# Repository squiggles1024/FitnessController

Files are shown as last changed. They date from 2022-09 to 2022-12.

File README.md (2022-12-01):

# FitnessController

This is an implementation of a BLE Gamepad. The purpose was to design a game pad that could be used while running on a treadmill. It would interface with a heartrate monitor strapped to someone's chest and it would pause your game and stop if your heart rate dropped below certain threshold. The microcontroller board is an B-L475E-IOT01A STM32 Discovery board. The firmware is a bare metal implementation of the "HID Over GATT" profile, which, at a minimum, requires a HID Service, Battery Service, and Device info service.
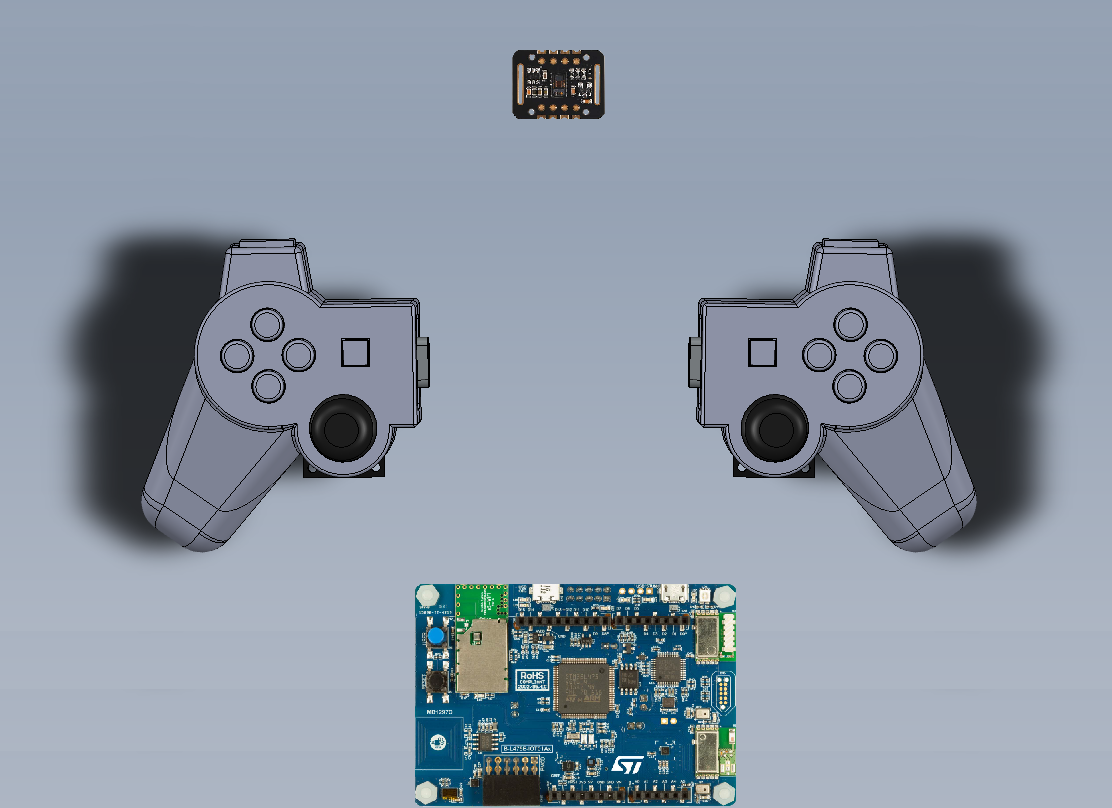
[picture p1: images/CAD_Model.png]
CAD Model Full

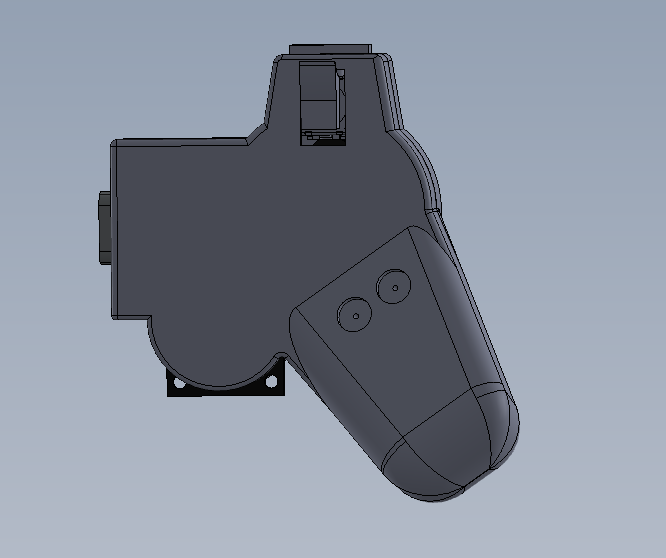
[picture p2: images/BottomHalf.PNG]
CAD Model Bottom


The mechanical design is my own, but it is clearly based on Sony's dual shock controller. I took a pair of calipers and took various measurements to imitate the design. Essentially I set out to cross the dualshock controller with a Wii Nunchuck by splitting a dual shock controller in two halves and putting a D-Sub connector on the sides. The joystick is an off-the-shelf joystick module which I cut the corners off of to make it fit in the housing. The triggers are also joystick modules, but turned upside down and mechanically secured such that it can only move along a single axis. This is a "PCBless" design, all the leads on the components are tied directly to the connector, and wires are spliced together so they can share power/ground signals.
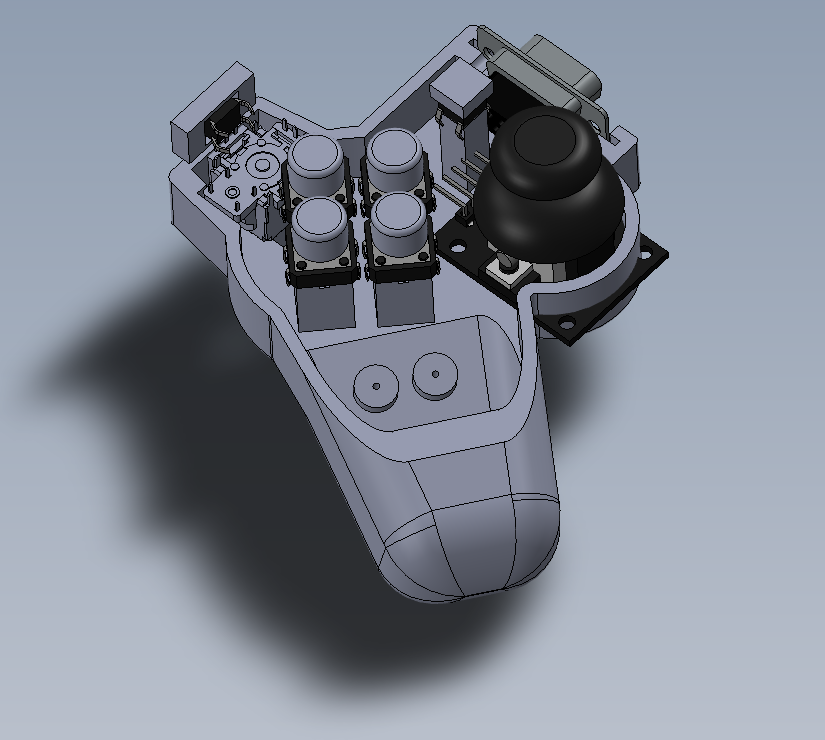
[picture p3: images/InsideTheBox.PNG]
CAD Model Inside


Known Issues: The heart rate monitor is currently NYI as I attempt to debug a hardfault that occurs during initialization of the I2C bus. Currently it only works with Linux based devices, (Windows not yet tested), and does not work with iOS. The controller does not show up to pair with iOS devices when it advertises itself. Likely it does not meet Apple's security requirements, but I haven't found any iOS BLE HID developement guidelines from Apple so I don't know for certain. All I've found is: "BLE HID data is consumed at the OS Kernel level of iOS" which only explains why it won't show up using the LightBlue BLE scanner app.

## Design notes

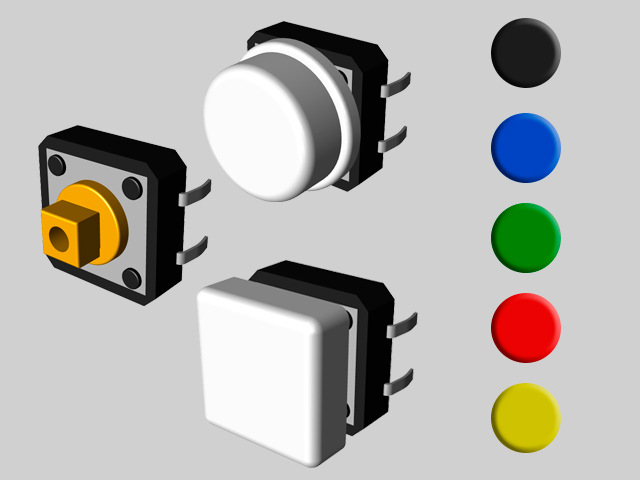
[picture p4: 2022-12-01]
CAD Models/12mm-button-without-cap-with-round-square-cap-1.snapshot.3/img.jpg

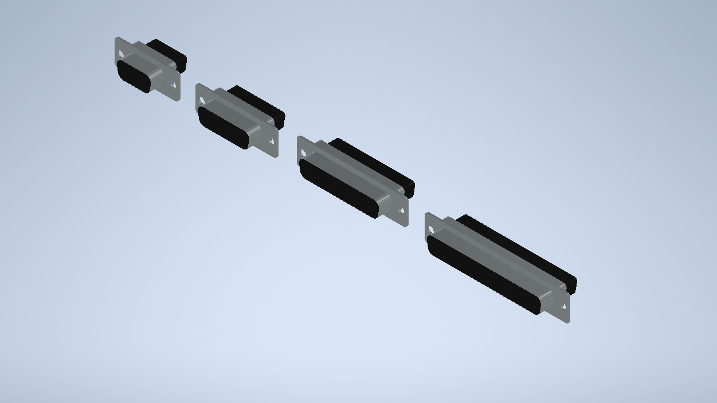
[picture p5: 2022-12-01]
CAD Models/d-sub-connector-femaile-1.snapshot.1/femaile/db.PNG

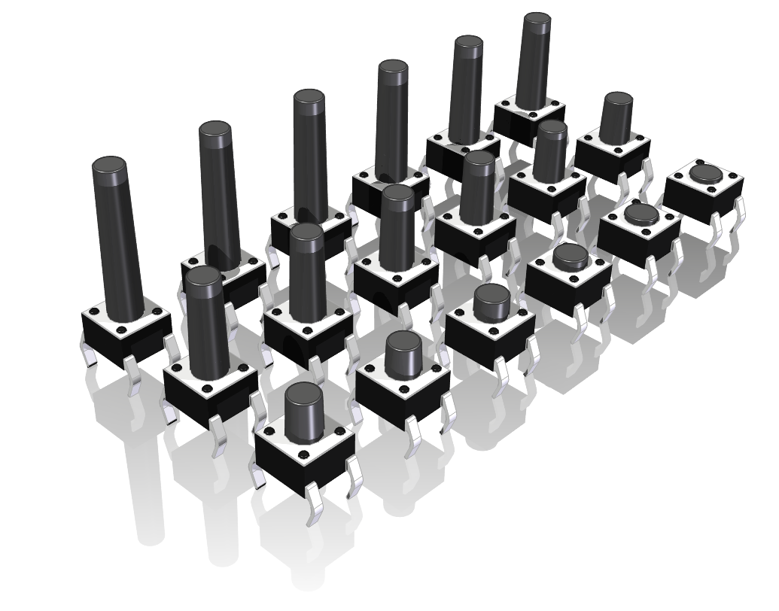
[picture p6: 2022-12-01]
CAD Models/tactile-switch-thru-6mm-series-1.snapshot.25/6x6mm - Thru.PNG

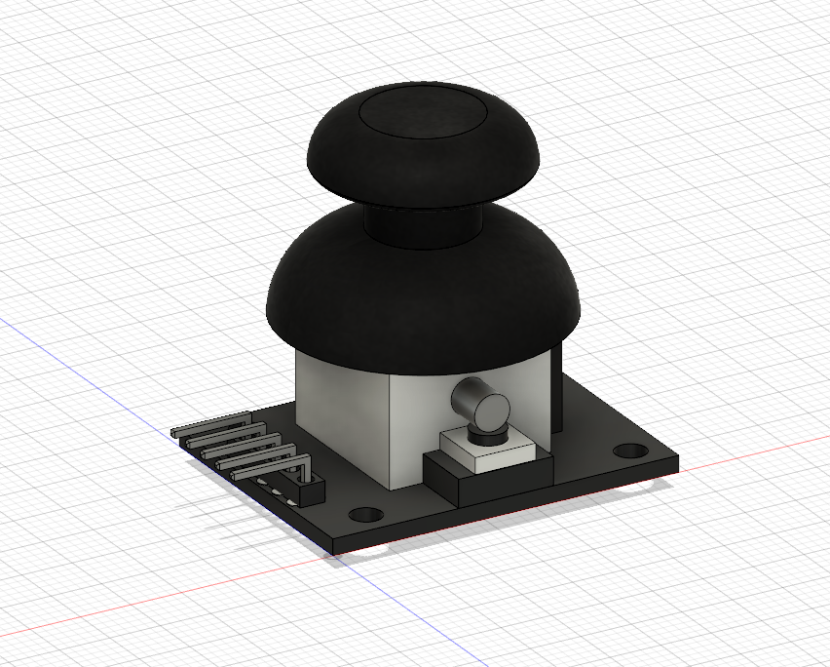
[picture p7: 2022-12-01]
CAD Models/joy-stick-4.snapshot.1 (1)/joy_stick_a2/joy_stick_2a.PNG

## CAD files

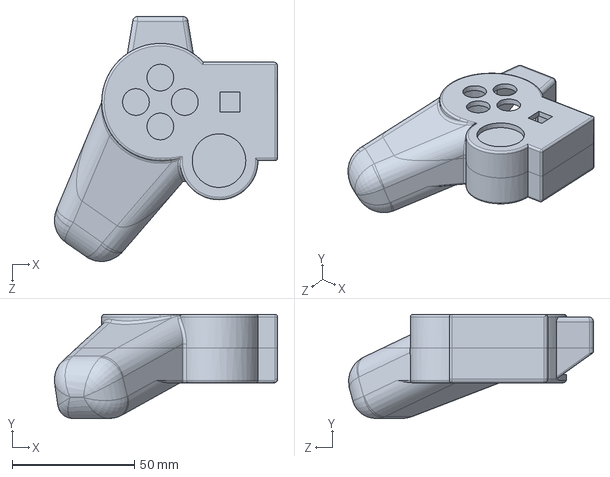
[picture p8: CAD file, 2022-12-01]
CAD Models/Nunchuck2_assembly.SLDASM
91.4 x 42.6 x 100.3 mm

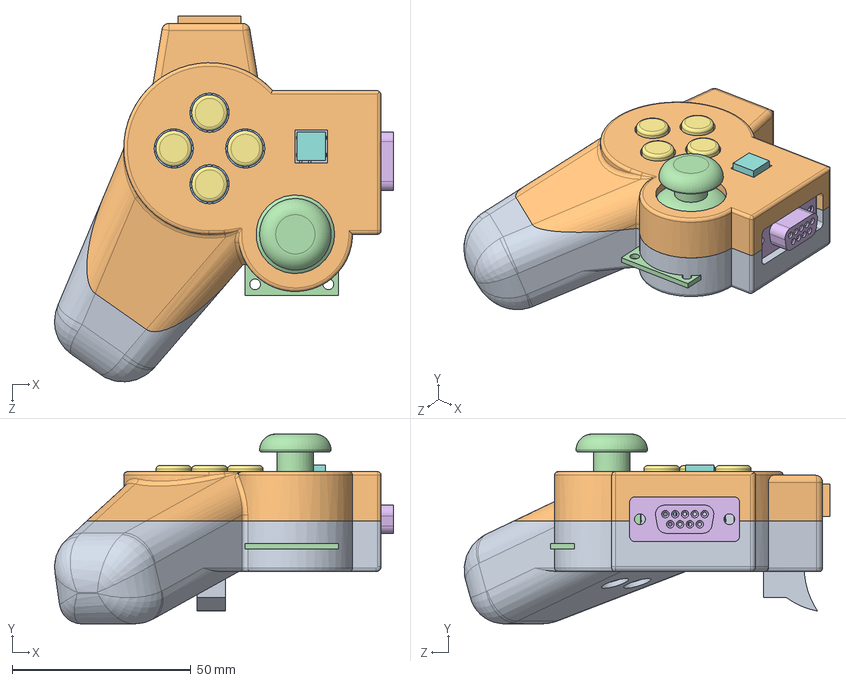
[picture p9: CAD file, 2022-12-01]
CAD Models/Nunchuck_Assy3.SLDASM
94.8 x 53.1 x 102.3 mm
Nunchuck_Buttom
NunChuck_Top
12mmx12mm Without cap.stp x 4
joy_stick_2a.step
Tactal Switch -Thru (6mmx 6mmx5.0mm).stp x 2
THB001P_PART8.stp
THB001P_PART7.stp
THB001P_PART6.stp
THB001P_PART5.stp
THB001P_PART4.stp
THB001P_PART3.stp
THB001P_PART2.stp
THB001P_PART1.stp
db9.stp
Button_Nunchuck x 4
StartButton^Nunchuck_Assy3
Trigger
Part1^Nunchuck_Assy3

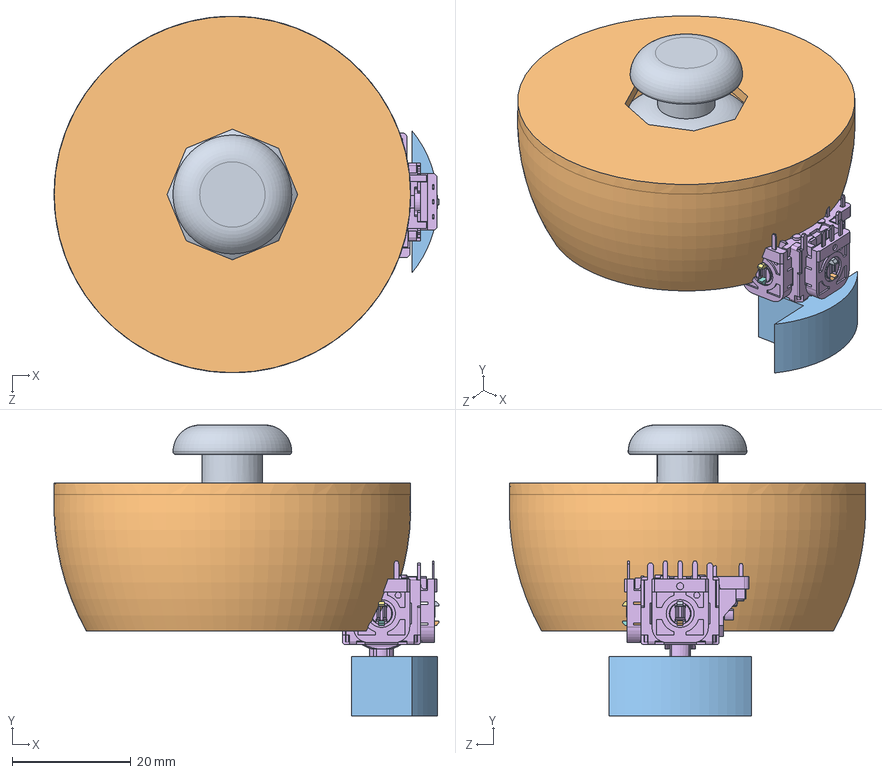
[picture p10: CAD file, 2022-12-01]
CAD Models/Nunchuck1.SLDASM
64.8 x 49.0 x 60.0 mm
joy_stick_2a.step
Part2^Nunchuck1
THB001P_PART8.stp
THB001P_PART7.stp
THB001P_PART6.stp
THB001P_PART5.stp
THB001P_PART4.stp
THB001P_PART3.stp
THB001P_PART2.stp
THB001P_PART1.stp
Part13^Nunchuck1

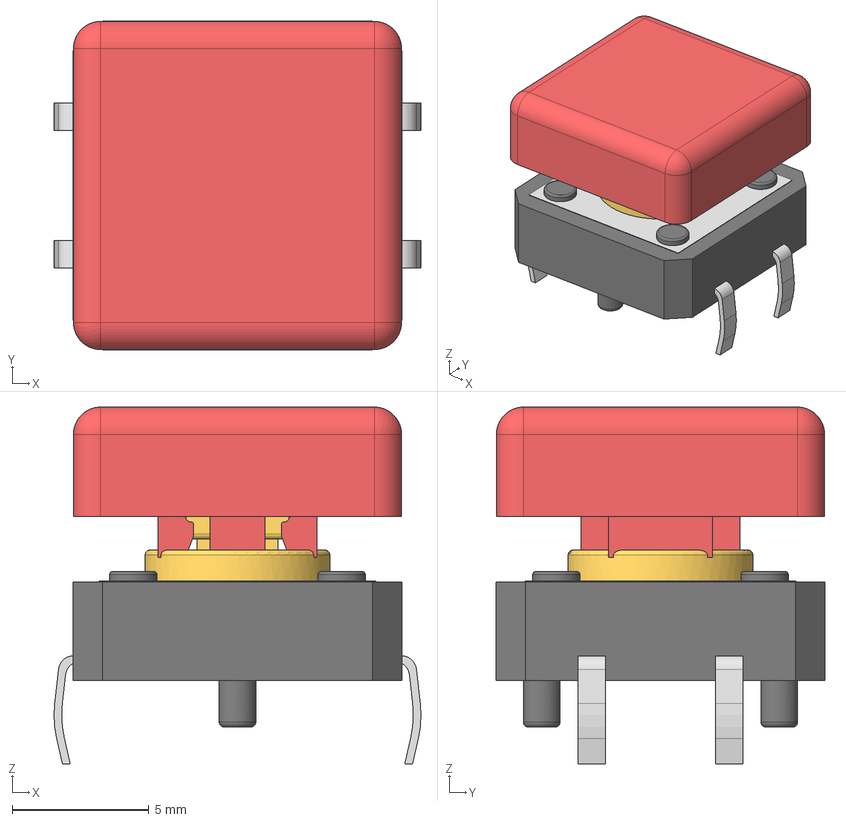
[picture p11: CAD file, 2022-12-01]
CAD Models/12mm-button-without-cap-with-round-square-cap-1.snapshot.3/12mmx12mm With Red cap square.stp
13.4 x 12.0 x 13.0 mm

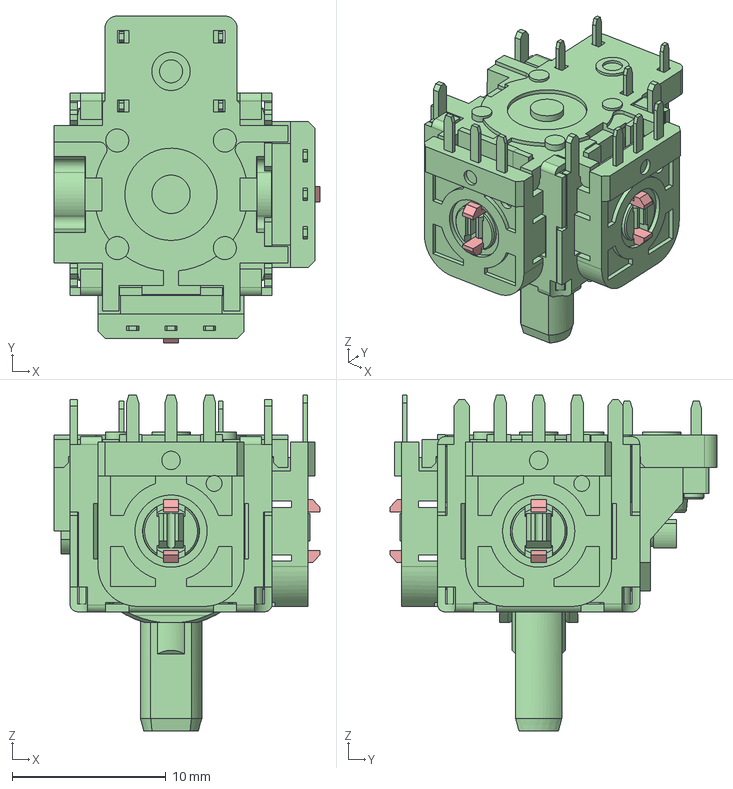
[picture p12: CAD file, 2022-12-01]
CAD Models/CKCOMPONENTS_THB001P/THB001P.stp
17.3 x 21.3 x 21.9 mm
THB001P_PART8
THB001P_PART7
THB001P_PART6
THB001P_PART5
THB001P_PART4
THB001P_PART3
THB001P_PART2
THB001P_PART1

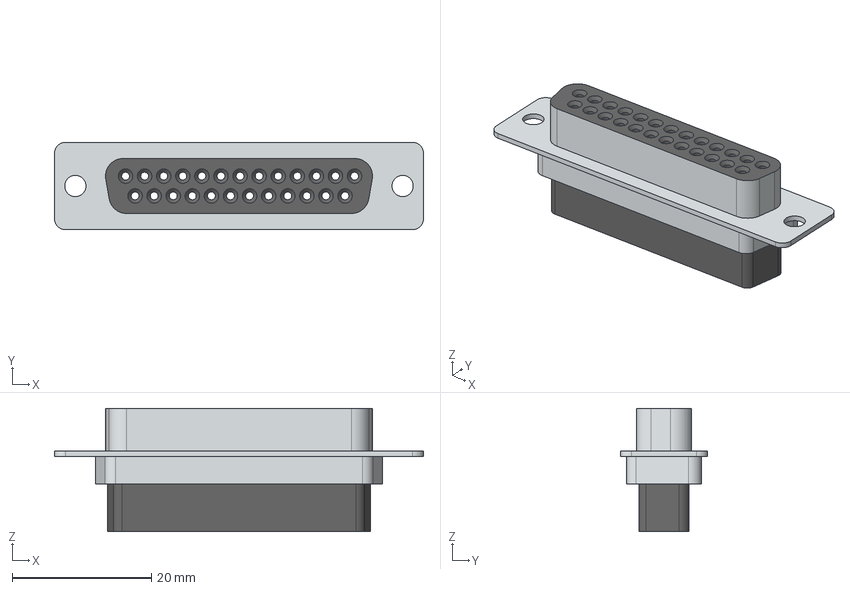
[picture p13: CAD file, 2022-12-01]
CAD Models/d-sub-connector-femaile-1.snapshot.1/femaile/db25.stp
53.0 x 12.5 x 17.7 mm

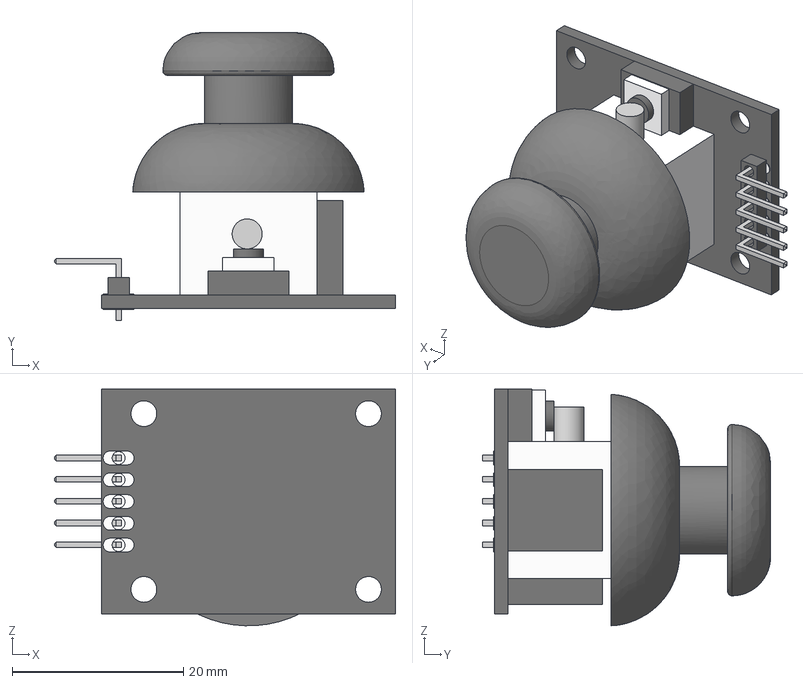
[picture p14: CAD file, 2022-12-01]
CAD Models/joy-stick-4.snapshot.1 (1)/joy_stick_a2/joy_stick_a2.iges
39.8 x 33.6 x 27.6 mm

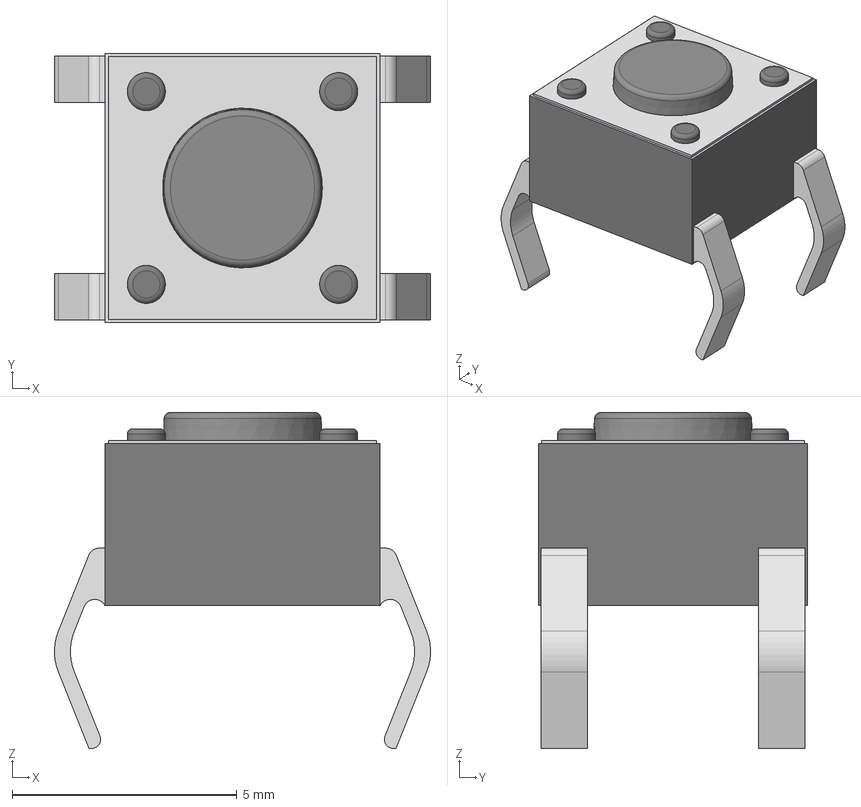
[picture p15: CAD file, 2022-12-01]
CAD Models/tactile-switch-thru-6mm-series-1.snapshot.25/Tactal Switch -Thru (6mmx 6mmx4.3mm).stp
8.37 x 5.99 x 7.48 mm

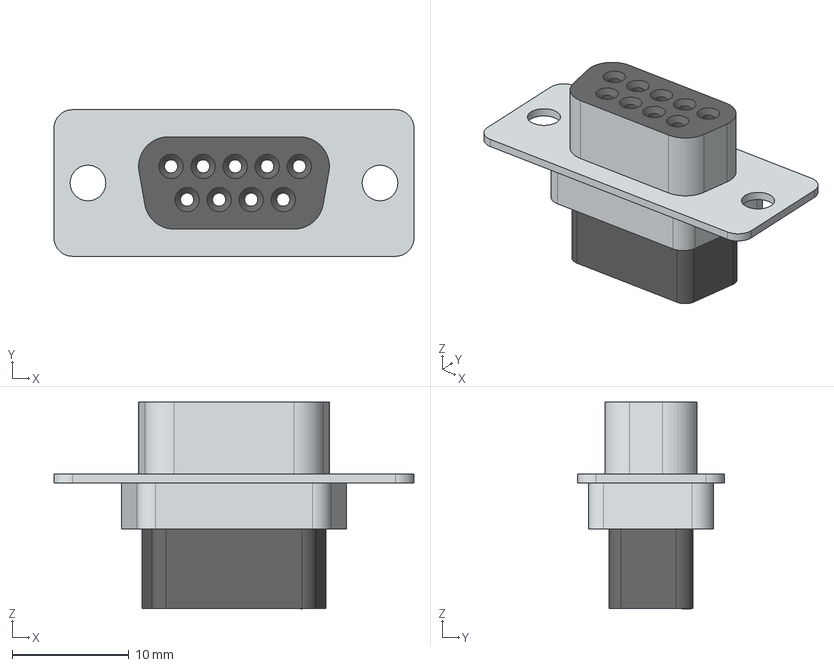
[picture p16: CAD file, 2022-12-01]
CAD Models/d-sub-connector-femaile-1.snapshot.1/femaile/db9.stp
30.8 x 12.5 x 17.7 mm

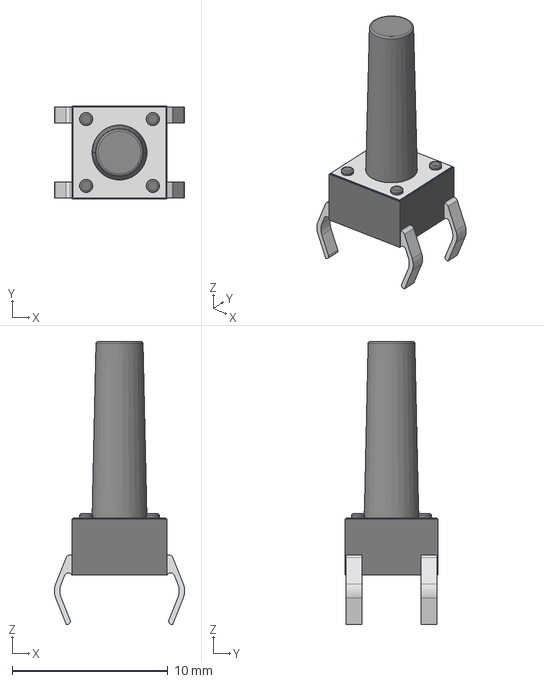
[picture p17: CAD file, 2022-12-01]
CAD Models/tactile-switch-thru-6mm-series-1.snapshot.25/Tactal Switch -Thru (6mmx 6mmx15.0mm).stp
8.37 x 5.99 x 18.2 mm

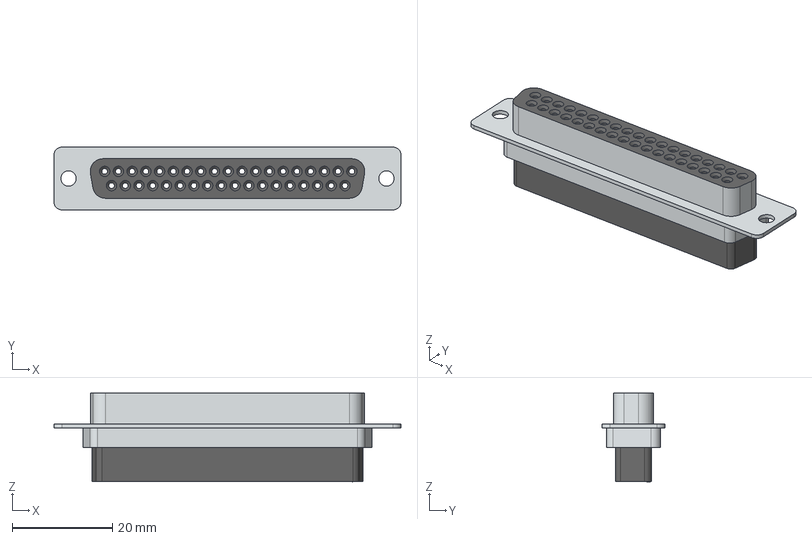
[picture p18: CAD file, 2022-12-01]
CAD Models/d-sub-connector-femaile-1.snapshot.1/femaile/db37.stp
69.3 x 12.5 x 17.7 mm

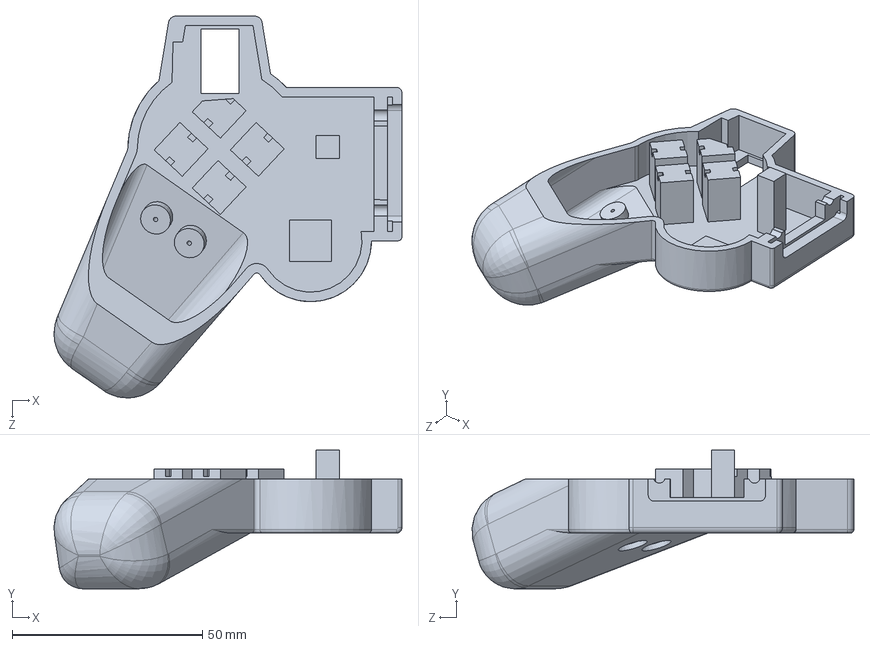
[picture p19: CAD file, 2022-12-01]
CAD Models/Nunchuck_Buttom.SLDPRT
91.4 x 36.4 x 100.3 mm

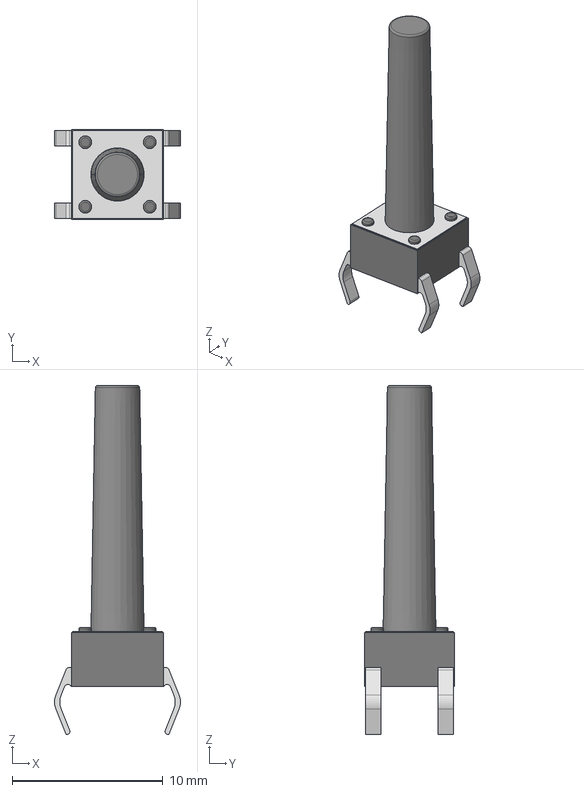
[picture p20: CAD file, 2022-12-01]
CAD Models/tactile-switch-thru-6mm-series-1.snapshot.25/Tactal Switch -Thru (6mmx 6mmx20.0mm).stp
8.37 x 5.99 x 23.2 mm

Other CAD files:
CAD Models/Nunchuck2_Assy.SLDPRT
CAD Models/Button_Nunchuck.SLDPRT
CAD Models/12mm-button-without-cap-with-round-square-cap-1.snapshot.3/12mmx12mm With Yellow cap square.stp
CAD Models/joy-stick-4.snapshot.1 (1)/joy_stick_a2/joy_stick_2a.step
CAD Models/12mm-button-without-cap-with-round-square-cap-1.snapshot.3/12mmx12mm With Green cap square.stp
CAD Models/12mm-button-without-cap-with-round-square-cap-1.snapshot.3/12mmx12mm With Black cap round.stp
CAD Models/12mm-button-without-cap-with-round-square-cap-1.snapshot.3/12mmx12mm With Black cap square.stp
CAD Models/12mm-button-without-cap-with-round-square-cap-1.snapshot.3/12mmx12mm With Blue cap round.stp
CAD Models/12mm-button-without-cap-with-round-square-cap-1.snapshot.3/12mmx12mm With Blue cap square.stp
CAD Models/12mm-button-without-cap-with-round-square-cap-1.snapshot.3/12mmx12mm With Green cap round.stp
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

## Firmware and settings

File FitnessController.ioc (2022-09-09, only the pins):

Mcu.UserName=STM32L475VGTx
PA0.GPIO_Label=XINPUT_GAMEPAD_B
PA0.Signal=GPIO_Input
PA1.GPIO_Label=XINPUT_GAMEPAD_A
PA1.Signal=GPIO_Input
PA10.GPIO_Label=USB_OTG_FS_ID
PA10.Signal=USB_OTG_FS_ID
PA11.GPIO_Label=USB_OTG_FS_DM
PA11.Signal=USB_OTG_FS_DM
PA12.GPIO_Label=USB_OTG_FS_DP
PA12.Signal=USB_OTG_FS_DP
PA2.GPIO_Label=XINPUT_GAMEPAD_DPAD_UP
PA2.Signal=GPIO_Input
PA3.GPIO_Label=XINPUT_GAMEPAD_START
PA3.Signal=GPIO_Input
PA4.GPIO_Label=XINPUT_GAMEPAD_RIGHT_THUMB
PA4.Signal=GPIO_Input
PA5.GPIO_Label=XINPUT_GAMEPAD_DPAD_RIGHT
PA5.Signal=GPIO_Input
PA6.GPIO_Label=XINPUT_GAMEPAD_DPAD_LEFT
PA6.Signal=GPIO_Input
PA7.GPIO_Label=XINPUT_GAMEPAD_DPAD_DOWN
PA7.Signal=GPIO_Input
PA8.GPIO_Label=SPBTLE_RF_RST
PA8.Signal=GPIO_Output
PA9.GPIO_Label=USB_OTG_FS_VBUS [STMPS2141STR_OUT]
PA9.Signal=USB_OTG_FS_VBUS
PB0.GPIO_Label=XINPUT_GAMEPAD_Y
PB0.Signal=GPIO_Input
PB1.GPIO_Label=XINPUT_GAMEPAD_LEFT_THUMB
PB1.Signal=GPIO_Input
PB14.GPIO_Label=LED2 [LED_GREEN]
PB14.Signal=GPIO_Output
PB2.GPIO_Label=XINPUT_GAMEPAD_LEFT_SHOULDER
PB2.Signal=GPIO_Input
PB6.GPIO_Label=ST_LINK_UART1_TX
PB6.Signal=USART1_TX
PB7.GPIO_Label=ST_LINK_UART1_RX
PB7.Signal=USART1_RX
PB8.GPIO_Label=ARD_D15 [I2C1_SCL]
PB8.Signal=I2C1_SCL
PB9.GPIO_Label=ARD_D14 [I2C1_SDA]
PB9.Signal=I2C1_SDA
PC0.GPIO_Label=LeftStick_X
PC0.Signal=ADCx_IN1
PC1.GPIO_Label=LeftStick_Y
PC1.Signal=ADCx_IN2
PC10.GPIO_Label=INTERNAL_SPI3_SCK [BT module_SPI_SCLK] [ISM43362_SCK]
PC10.Signal=SPI3_SCK
PC11.GPIO_Label=INTERNAL_SPI3_MISO [BT module_SPI_MISO] [ISM43362_MISO]
PC11.Signal=SPI3_MISO
PC12.GPIO_Label=INTERNAL_SPI3_MOSI [BT module_SPI_MOSI] [ISM43362_MOSI]
PC12.Signal=SPI3_MOSI
PC2.GPIO_Label=RightStick_X
PC2.Signal=ADCx_IN3
PC3.GPIO_Label=RightStick_Y
PC3.Signal=ADCx_IN4
PC4.GPIO_Label=LeftTrigger
PC4.Signal=ADCx_IN13
PC5.GPIO_Label=RightTrigger
PC5.Signal=ADCx_IN14
PC9.GPIO_Label=LED3_WIFI_ LED4_BLE
PC9.Signal=GPIO_Output
PD13.GPIO_Label=SPBTLE_RF_SPI3_CSN [BT module_SPI_CS]
PD13.Signal=GPIO_Output
PD14.GPIO_Label=XINPUT_GAMEPAD_X
PD14.Signal=GPIO_Input
PE6.GPIO_Label=SPBTLE_RF_IRQ_EXTI6 [BT module_SPI_IRQ]
PE6.Signal=GPXTI6

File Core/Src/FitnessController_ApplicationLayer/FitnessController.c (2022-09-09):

/*
 * FitnessController.c
 *
 *  Created on: Jul 11, 2022
 *      Author: evanl
 */


#include <stdint.h>
#include <stdio.h>
#include "bluenrg_utils.h"
#include "bluenrg_conf.h"
#include "hci.h"
#include "bluenrg_types.h"
#include "bluenrg_gap.h"
#include "bluenrg_aci.h"
#include "bluenrg_gap_aci.h"
#include "sm.h"
#include "hci_le.h"
#include "FitnessController.h"
#include "HIDService.h"
#include "BatteryService.h"
#include "DeviceInfoService.h"
#include "HID.h"
#include "MAX30102.h"

#define DEVICE_CONNECTABLE (1)
#define DEVICE_CONNECTED (0)
#define DEVICE_DISCOVERABLE (1)
#define DEVICE_NOTDISCOVERABLE (0)
#define XINPUT_LEFT_THUMB_INDEX  (6U)
#define XINPUT_RIGHT_THUMB_INDEX (7U)
#define XINPUT_LEFTANALOG_INDEX (0U)
#define XINPUT_RIGHTANALOG_INDEX (1U)

FitnessControllerHandle_t FitnessController;
MAX30102_Handle_t HeartRateMonitor;

static const uint8_t SERVER_BDADDR[] = {0x01, 0x02, 0x03, 0x04, 0x05, 0x06};
static const char local_name[] = {AD_TYPE_COMPLETE_LOCAL_NAME,'F', 'i', 't', 'n', 'e','s','s',' ','C','o','n','t','r','o','l','l','e','r'};
static uint16_t connection_handle = 0xFFFF;
static uint8_t connected = DEVICE_CONNECTABLE;
static uint8_t discoverable = DEVICE_NOTDISCOVERABLE;
static void AddServices(void);
static tBleStatus SetDiscoverable(void);
static void ControllerEventNotify(void *pData);
static void ControllerButtonInit(FitnessControllerHandle_t *FitnessController);
static void ControllerTriggerInit(FitnessControllerHandle_t *FitnessController);
static void ControllerStickInit(FitnessControllerHandle_t *FitnessController);
static void ControllerDpadInit(FitnessControllerHandle_t *FitnessController);
static void HeartRateInit(FitnessControllerHandle_t *FitnessController);
static const uint16_t ButtonMskLUT[NUMBER_OF_BUTTONS] = {
		0x0001, //a
		0x0002, //b
		0x0004, //x
		0x0008, //y
		0x0010, //start
		0x0020, //back
		0x0040, //left thumb
		0x0080, //right thumb
		0x0100, //left shoulder
		0x0200  //right shoulder
};


void FitnessControllerBLEInit(void){
	tBleStatus status; //Var for storing return status

	uint8_t bdaddr[BD_ADDR_SIZE]; //Device address
	const char *DeviceName = "Evan's Fitness Controller"; //Device Name
	uint16_t service_handle, dev_name_char_handle, appearance_char_handle;
	uint8_t hwVersion;
	uint16_t fwVersion;

	BLUENRG_memcpy(bdaddr, SERVER_BDADDR, sizeof(SERVER_BDADDR));
	//Init HCI
	hci_init(ControllerEventNotify,NULL);
	getBlueNRGVersion(&hwVersion, &fwVersion);
	hci_reset();
	HAL_Delay(100);

	status = aci_hal_write_config_data(CONFIG_DATA_PUBADDR_OFFSET, CONFIG_DATA_PUBADDR_LEN, bdaddr);

	if(status != BLE_STATUS_SUCCESS){
		printf("aci_hal_write_config_data failed\n\r");
		while(1);
	}

	status = aci_gatt_init();
	if(status != BLE_STATUS_SUCCESS){
		printf("aci_gatt_init failed\n\r");
		while(1);
	}


    status = aci_gap_init_IDB05A1(GAP_PERIPHERAL_ROLE_IDB05A1, 0, strlen(DeviceName), &service_handle, &dev_name_char_handle, &appearance_char_handle);
	if(status != BLE_STATUS_SUCCESS){
		printf("aci_gap_init failed\n\r");
		while(1);
	}


	status = aci_gatt_update_char_value(service_handle, dev_name_char_handle, 0, strlen(DeviceName), DeviceName);
	if(status != BLE_STATUS_SUCCESS){
		printf("aci_gatt_update_char_value failed\n\r");
		while(1);
	}
	uint16_t test_appearance_value = 0x03C4;
	status = aci_gatt_update_char_value(service_handle,appearance_char_handle,0,2,&test_appearance_value);
	AddServices();

	status = aci_gap_set_io_capability(IO_CAP_NO_INPUT_NO_OUTPUT);
	if(status != BLE_STATUS_SUCCESS){
        printf("aci_gap_set_io_capabilities failed\n\r");
	}
	status = aci_gap_set_auth_requirement(MITM_PROTECTION_NOT_REQUIRED,
			                              OOB_AUTH_DATA_ABSENT,
			                              NULL,
										  7,
										  16,
										  USE_FIXED_PIN_FOR_PAIRING,
										  123456,
										  NO_BONDING);
	if(status != BLE_STATUS_SUCCESS){
        printf("aci_gap_set_auth_requirement failed\n\r");
	}


}

void FitnessController_BLE_Process(void){
	//make device discoverable
	if(discoverable == DEVICE_NOTDISCOVERABLE){
		SetDiscoverable();
	}
	FitnessControllerDataFlag_t DataFlag = FitnessControllerUpdateState(&FitnessController);
    if(DataFlag == FC_NewDataAvailable){
    	SendHIDData();
    }
	hci_user_evt_proc();
}

void FitnessControllerHardwareInit(FitnessControllerHandle_t *FitnessController){
	ControllerButtonInit(FitnessController);
	ControllerTriggerInit(FitnessController);
	ControllerStickInit(FitnessController);
	ControllerDpadInit(FitnessController);
	//HeartRateInit(FitnessController);
}

FitnessControllerDataFlag_t FitnessControllerUpdateState(FitnessControllerHandle_t *FitnessController){
	FitnessControllerDataFlag_t ReturnStatus = FC_NoDataAvailable;
    for(uint8_t i = 0; i < NUMBER_OF_BUTTONS; i++){
    	if(ButtonRead(&FitnessController->Buttons[i].Button) == ButtonChanged){
    		ReturnStatus |= FC_NewDataAvailable;
            if(FitnessController->Buttons[i].Button.State == ButtonPressed){
            	HIDReport.Buttons |= FitnessController->Buttons[i].ButtonMsk;
            } else {
            	HIDReport.Buttons &= ~(FitnessController->Buttons[i].ButtonMsk);
            }
    	}
    }

    for(uint8_t i = 0; i < NUMBER_OF_TRIGGERS; i++){
        if(TriggerRead(&FitnessController->Triggers[i]) == TriggerChanged){
        	ReturnStatus |= FC_NewDataAvailable;
        	HIDReport.Triggers[i] = FitnessController->Triggers[i].Position;
        }
    }

    for(uint8_t i = 0; i < NUMBER_OF_STICKS; i++){
        if(AnalogStickRead(&FitnessController->Sticks[i]) == AnalogStickChanged){
        	ReturnStatus |= FC_NewDataAvailable;
        	HIDReport.Sticks[i*2] = FitnessController->Sticks[i].X_Position;
        	HIDReport.Sticks[i*2+1] = FitnessController->Sticks[i].Y_Position;
        }
    }
    if(DpadRead(&FitnessController->Dpad) == DpadChanged){
    	ReturnStatus |= FC_NewDataAvailable;
    	HIDReport.Dpad = FitnessController->Dpad.State;
    }

    //MAX30102_ReadHeartRate(&HeartRateMonitor);

    return ReturnStatus;
}

static void AddServices(void){

	  HIDServiceStatus_t HIDStatus;
	  HIDStatus = AddHIDService();
	  if(HIDStatus != HID_OK){
          printf("Add HID Service Failed\n\r");
          while(1);
	  }

	  BatteryServiceStatus_t BatStatus;
	  BatStatus = AddBatteryService();
	  if(BatStatus != Battery_OK){
		  printf("Add Battery Service Failed\n\r");
          while(1);
	  }

	  DeviceInfoServiceStatus_t DIStatus;
	  DIStatus = AddDeviceInfoService();
	  if(DIStatus != DeviceInfo_OK){
		  printf("Add Device Service Failed\n\r");
          while(1);
	  }

}

static tBleStatus SetDiscoverable(void){
	tBleStatus status;
    status = aci_gap_set_discoverable(ADV_IND, 0, 0, PUBLIC_ADDR, NO_WHITE_LIST_USE, sizeof(local_name), local_name, 0, NULL, 0, 0);
    if(status == BLE_STATUS_SUCCESS){
    	discoverable = DEVICE_DISCOVERABLE;
    }

	if(status != BLE_STATUS_SUCCESS){
		printf("aci_gap_set_discoverable failed\n\r");
	}

	return status;
}
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

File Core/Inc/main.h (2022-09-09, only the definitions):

#define SPBTLE_RF_IRQ_EXTI6_Pin GPIO_PIN_6
#define SPBTLE_RF_IRQ_EXTI6_GPIO_Port GPIOE
#define SPBTLE_RF_IRQ_EXTI6_EXTI_IRQn EXTI9_5_IRQn
#define LeftStick_X_Pin GPIO_PIN_0
#define LeftStick_X_GPIO_Port GPIOC
#define LeftStick_Y_Pin GPIO_PIN_1
#define LeftStick_Y_GPIO_Port GPIOC
#define RightStick_X_Pin GPIO_PIN_2
#define RightStick_X_GPIO_Port GPIOC
#define RightStick_Y_Pin GPIO_PIN_3
#define RightStick_Y_GPIO_Port GPIOC
#define XINPUT_GAMEPAD_B_Pin GPIO_PIN_0
#define XINPUT_GAMEPAD_B_GPIO_Port GPIOA
#define XINPUT_GAMEPAD_A_Pin GPIO_PIN_1
#define XINPUT_GAMEPAD_A_GPIO_Port GPIOA
#define XINPUT_GAMEPAD_DPAD_UP_Pin GPIO_PIN_2
#define XINPUT_GAMEPAD_DPAD_UP_GPIO_Port GPIOA
#define XINPUT_GAMEPAD_START_Pin GPIO_PIN_3
#define XINPUT_GAMEPAD_START_GPIO_Port GPIOA
#define XINPUT_GAMEPAD_RIGHT_THUMB_Pin GPIO_PIN_4
#define XINPUT_GAMEPAD_RIGHT_THUMB_GPIO_Port GPIOA
#define XINPUT_GAMEPAD_DPAD_RIGHT_Pin GPIO_PIN_5
#define XINPUT_GAMEPAD_DPAD_RIGHT_GPIO_Port GPIOA
#define XINPUT_GAMEPAD_DPAD_LEFT_Pin GPIO_PIN_6
#define XINPUT_GAMEPAD_DPAD_LEFT_GPIO_Port GPIOA
#define XINPUT_GAMEPAD_DPAD_DOWN_Pin GPIO_PIN_7
#define XINPUT_GAMEPAD_DPAD_DOWN_GPIO_Port GPIOA
#define LeftTrigger_Pin GPIO_PIN_4
#define LeftTrigger_GPIO_Port GPIOC
#define RightTrigger_Pin GPIO_PIN_5
#define RightTrigger_GPIO_Port GPIOC
#define XINPUT_GAMEPAD_Y_Pin GPIO_PIN_0
#define XINPUT_GAMEPAD_Y_GPIO_Port GPIOB
#define XINPUT_GAMEPAD_LEFT_THUMB_Pin GPIO_PIN_1
#define XINPUT_GAMEPAD_LEFT_THUMB_GPIO_Port GPIOB
#define XINPUT_GAMEPAD_LEFT_SHOULDER_Pin GPIO_PIN_2
#define XINPUT_GAMEPAD_LEFT_SHOULDER_GPIO_Port GPIOB
#define LED2_Pin GPIO_PIN_14
#define LED2_GPIO_Port GPIOB
#define SPBTLE_RF_SPI3_CSN_Pin GPIO_PIN_13
#define SPBTLE_RF_SPI3_CSN_GPIO_Port GPIOD
#define XINPUT_GAMEPAD_X_Pin GPIO_PIN_14
#define XINPUT_GAMEPAD_X_GPIO_Port GPIOD
#define LED3_WIFI__LED4_BLE_Pin GPIO_PIN_9
#define LED3_WIFI__LED4_BLE_GPIO_Port GPIOC
#define SPBTLE_RF_RST_Pin GPIO_PIN_8
#define SPBTLE_RF_RST_GPIO_Port GPIOA
#define USB_OTG_FS_VBUS_Pin GPIO_PIN_9
#define USB_OTG_FS_VBUS_GPIO_Port GPIOA
#define USB_OTG_FS_ID_Pin GPIO_PIN_10
#define USB_OTG_FS_ID_GPIO_Port GPIOA
#define USB_OTG_FS_DM_Pin GPIO_PIN_11
#define USB_OTG_FS_DM_GPIO_Port GPIOA
#define USB_OTG_FS_DP_Pin GPIO_PIN_12
#define USB_OTG_FS_DP_GPIO_Port GPIOA
#define SYS_JTMS_SWDIO_Pin GPIO_PIN_13
#define SYS_JTMS_SWDIO_GPIO_Port GPIOA
#define SYS_JTCK_SWCLK_Pin GPIO_PIN_14
#define SYS_JTCK_SWCLK_GPIO_Port GPIOA
#define XINPUT_GAMEPAD_RIGHT_SHOULDER_Pin GPIO_PIN_15
#define XINPUT_GAMEPAD_RIGHT_SHOULDER_GPIO_Port GPIOA
#define INTERNAL_SPI3_SCK_Pin GPIO_PIN_10
#define INTERNAL_SPI3_SCK_GPIO_Port GPIOC
#define INTERNAL_SPI3_MISO_Pin GPIO_PIN_11
#define INTERNAL_SPI3_MISO_GPIO_Port GPIOC
#define INTERNAL_SPI3_MOSI_Pin GPIO_PIN_12
#define INTERNAL_SPI3_MOSI_GPIO_Port GPIOC
#define SYS_JTD0_SWO_Pin GPIO_PIN_3
#define SYS_JTD0_SWO_GPIO_Port GPIOB
#define XINPUT_GAMEPAD_BACK_Pin GPIO_PIN_4
#define XINPUT_GAMEPAD_BACK_GPIO_Port GPIOB
#define ST_LINK_UART1_TX_Pin GPIO_PIN_6
#define ST_LINK_UART1_TX_GPIO_Port GPIOB
#define ST_LINK_UART1_RX_Pin GPIO_PIN_7
#define ST_LINK_UART1_RX_GPIO_Port GPIOB
#define ARD_D15_Pin GPIO_PIN_8
#define ARD_D15_GPIO_Port GPIOB
#define ARD_D14_Pin GPIO_PIN_9
#define ARD_D14_GPIO_Port GPIOB

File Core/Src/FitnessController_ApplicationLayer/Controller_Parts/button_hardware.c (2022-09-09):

/*
 * button_hardware.c
 *
 *  Created on: Sep 2, 2022
 *      Author: evanl
 */
/**************************************//**************************************//**************************************
 * Includes
 **************************************//**************************************//**************************************/
#include "button_hardware.h"
#include "stm32l4xx_hal.h"
#include "gpio.h"


/**************************************//**************************************//**************************************
 * Enums
 **************************************//**************************************//**************************************/
typedef enum{
	ButtonIO_Uninitialized = 0,
	ButtonIO_Initialized
}Button_IO_InitStatus_t;

/**************************************//**************************************//**************************************
 * Private Structs
 **************************************//**************************************//**************************************/
typedef struct{
	GPIO_TypeDef *GPIOPort;
	uint16_t GPIOPin;
}ButtonGPIOWrapper_t;


/**************************************//**************************************//**************************************
 * Private Variables
 **************************************//**************************************//**************************************/
static Button_IO_InitStatus_t initialize_status = ButtonIO_Uninitialized;

static const ButtonGPIOWrapper_t ButtonGPIOLUT[NUMBER_OF_BUTTONS] = {
		{XINPUT_GAMEPAD_A_GPIO_Port, XINPUT_GAMEPAD_A_Pin},                           //1
		{XINPUT_GAMEPAD_B_GPIO_Port, XINPUT_GAMEPAD_B_Pin},                           //2
		{XINPUT_GAMEPAD_X_GPIO_Port, XINPUT_GAMEPAD_X_Pin},                           //3
		{XINPUT_GAMEPAD_Y_GPIO_Port, XINPUT_GAMEPAD_Y_Pin},                           //4
		{XINPUT_GAMEPAD_START_GPIO_Port, XINPUT_GAMEPAD_START_Pin},                   //5
		{XINPUT_GAMEPAD_BACK_GPIO_Port, XINPUT_GAMEPAD_BACK_Pin},                     //6
		{XINPUT_GAMEPAD_LEFT_THUMB_GPIO_Port, XINPUT_GAMEPAD_LEFT_THUMB_Pin},         //7
		{XINPUT_GAMEPAD_RIGHT_THUMB_GPIO_Port, XINPUT_GAMEPAD_RIGHT_THUMB_Pin},       //8
		{XINPUT_GAMEPAD_LEFT_SHOULDER_GPIO_Port, XINPUT_GAMEPAD_LEFT_SHOULDER_Pin},   //9
		{XINPUT_GAMEPAD_RIGHT_SHOULDER_GPIO_Port, XINPUT_GAMEPAD_RIGHT_SHOULDER_Pin}, //10

};
/**************************************//**************************************//**************************************
 * Private Function Definitions
 **************************************//**************************************//**************************************/
/**************************************//**************************************
 *@Brief: Initializes hardware devices needed to read a button state
 *@Params: None
 *@Return: None
 *@Precondition: None
 *@Postcondition: GPIO Peripheral and clocks will be enabled and ready to use
 **************************************//**************************************/
static void Button_IO_init(void){

	if(initialize_status == ButtonIO_Uninitialized){
		Button_GPIO_Init();
	    initialize_status = ButtonIO_Initialized;
	}
}

static void Button_IO_deinit(void){

	if(initialize_status == ButtonIO_Initialized){
	    //de init GPIO. implement later.
	    initialize_status = ButtonIO_Uninitialized;
	}
}

/**************************************//**************************************
 *@Brief: Reads the state of a button
 *@Params: Number of the button to read
 *@Return: ButtonUnpressed if the button is not pressed, ButtonPressed if it is pressed.
 *@Precondition: Button IO should be initialized
 *@Postcondition: None
 **************************************//**************************************/
static ButtonState_t Button_IO_ReadPosLogic(uint8_t ButtonNumber){
	GPIO_PinState State = HAL_GPIO_ReadPin(ButtonGPIOLUT[ButtonNumber].GPIOPort, ButtonGPIOLUT[ButtonNumber].GPIOPin);
	if(State == GPIO_PIN_SET){
		return ButtonPressed;
	} else {
		return ButtonUnpressed;
	}
}

static ButtonState_t Button_IO_ReadNegLogic(uint8_t ButtonNumber){
	GPIO_PinState State = HAL_GPIO_ReadPin(ButtonGPIOLUT[ButtonNumber].GPIOPort, ButtonGPIOLUT[ButtonNumber].GPIOPin);
	if(State == GPIO_PIN_SET){
		return ButtonUnpressed;
	} else {
		return ButtonPressed;
	}
}

/**************************************//**************************************//**************************************
 * Public Variables
 **************************************//**************************************//**************************************/
//MCP23017_Handle_t Expander[NUMBER_OF_IO_EXPANDERS];

const Button_IO_Drv_t ButtonIO_DriverPosLogic = {
		.init = Button_IO_init,
		.read = Button_IO_ReadPosLogic,
		.deinit = Button_IO_deinit,
		.write = '\0',
		.ioctl = '\0'
};

const Button_IO_Drv_t ButtonIO_DriverNegLogic = {
		.init = Button_IO_init,
		.read = Button_IO_ReadNegLogic,
		.deinit = Button_IO_deinit,
		.write = '\0',
		.ioctl = '\0'
};

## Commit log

2022-09-04 Add DMA functionality
2022-09-04 Update ADC to work in DMA Mode on 6 Channels
2022-09-04 Added Controller Hardware drivers
2022-09-04 Add Controller Hardware Drivers
2022-09-04 Add FitnessController driver
2022-09-07 Disable DMA Transfer Complete IRQ
2022-09-07 Remove filtering
2022-09-09 Reduce button qty to 10, Add Dpad support
2022-12-01 add CAD models and readme images
    [12mmx12mm With Black cap round.stp, 12mmx12mm With Black cap square.stp, 12mmx12mm With Blue cap round.stp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]

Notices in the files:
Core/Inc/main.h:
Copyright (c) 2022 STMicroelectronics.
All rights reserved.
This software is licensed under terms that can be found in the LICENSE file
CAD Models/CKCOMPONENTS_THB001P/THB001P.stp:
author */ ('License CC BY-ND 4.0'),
